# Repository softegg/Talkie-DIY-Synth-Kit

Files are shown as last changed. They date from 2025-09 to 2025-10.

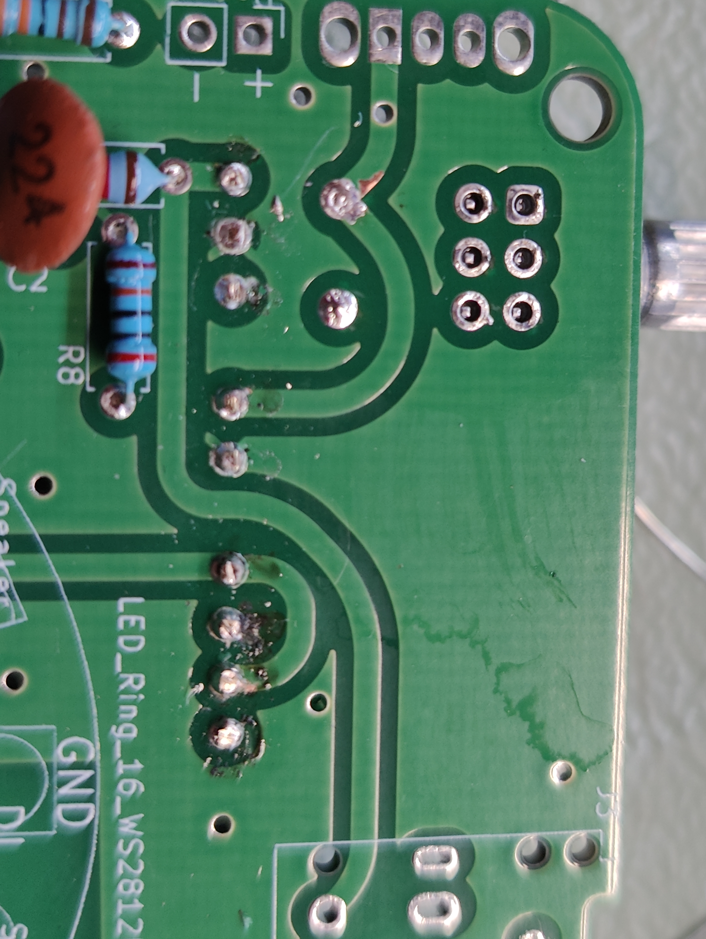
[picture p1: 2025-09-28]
docs/assembly pics/Step 3 amp board final pins.jpg

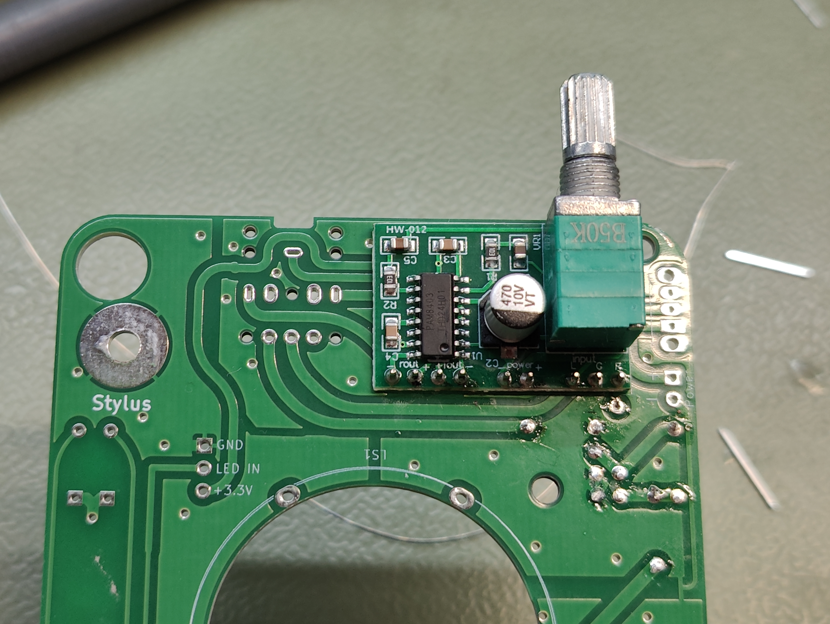
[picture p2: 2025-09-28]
docs/assembly pics/Step 3d amp board complete.jpg

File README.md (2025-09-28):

# Talkie-DIY-Synth-Kit
 Talkie is a DIY Handheld Virtual Analog Music Synthesizer Kit designed by Tina Belmont for the X-Days 2025 event at X-Hain hack+make space, Friedrichshain, Berlin.
 
 This project is based on the Vectorscope Synth ( https://github.com/softegg/Vectorscope-Synth ) made for a Hackaday Berlin 2024 workshop, which was based on the Stylish Trucker Belt Buckle Music Synthesizer ( https://github.com/softegg/Stylish-Trucker-Belt-Synthesizer ) originally made for MAGwest in 2018. Please find the Arduino source code in those projects.
 
 This project is licensed as non-commercial use only. Individuals can use the code and designs to make and modify their own synthesizers, but they cannot sell them without a license from me.
 
 No warranty of correctness or suitablility or safety is provided or honored for this project. Use at your own risk.

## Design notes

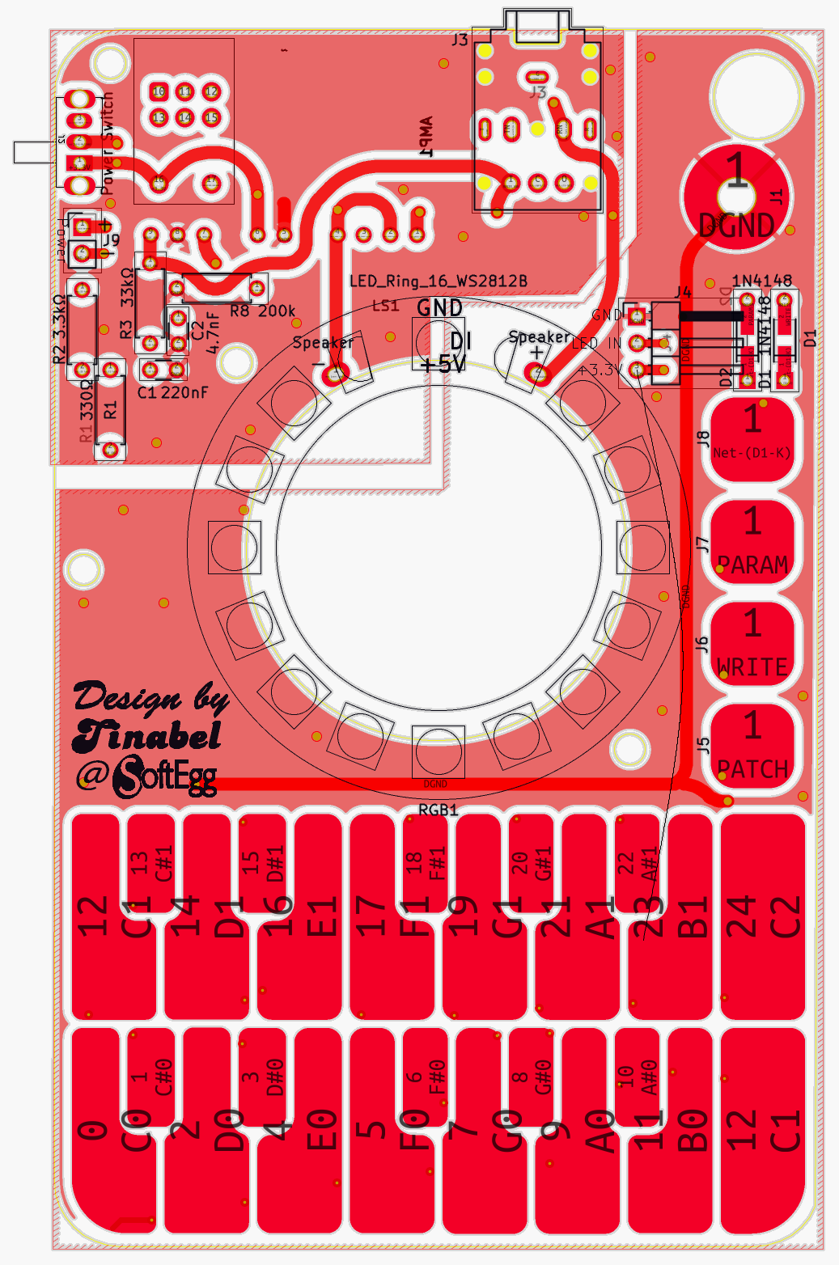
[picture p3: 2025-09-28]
docs/PCB Front + silkscreen.PNG

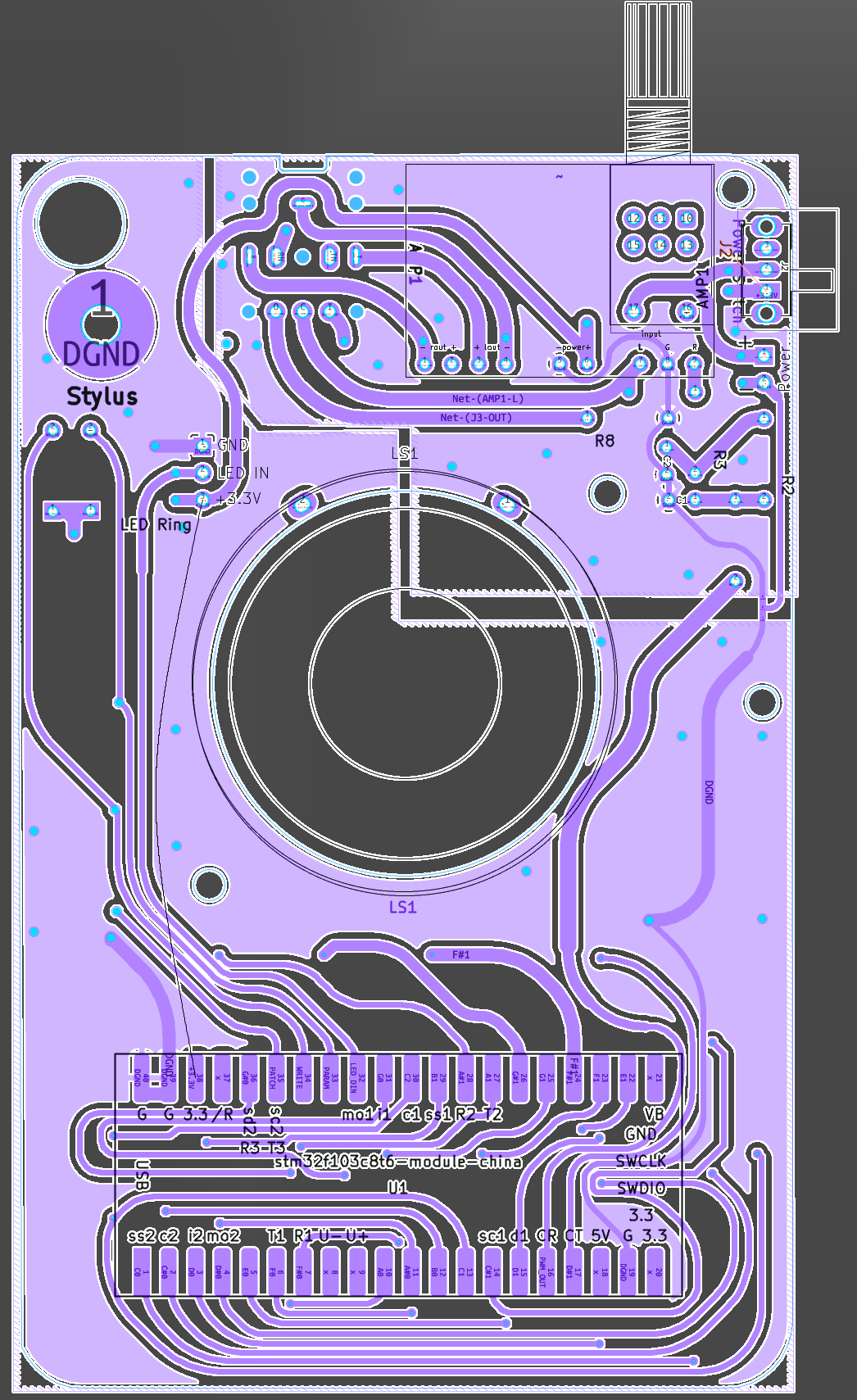
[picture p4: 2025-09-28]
docs/PCB Back + silkscreen and nets.PNG

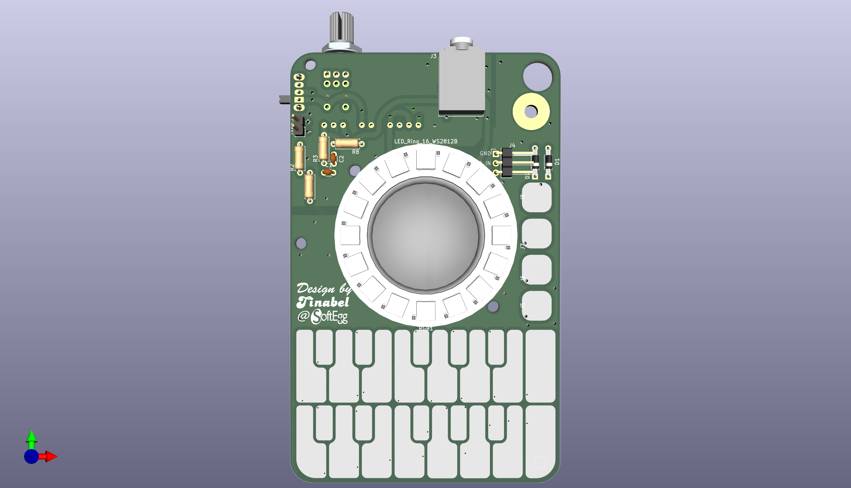
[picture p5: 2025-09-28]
renders/X-DaysSynth-Front.png

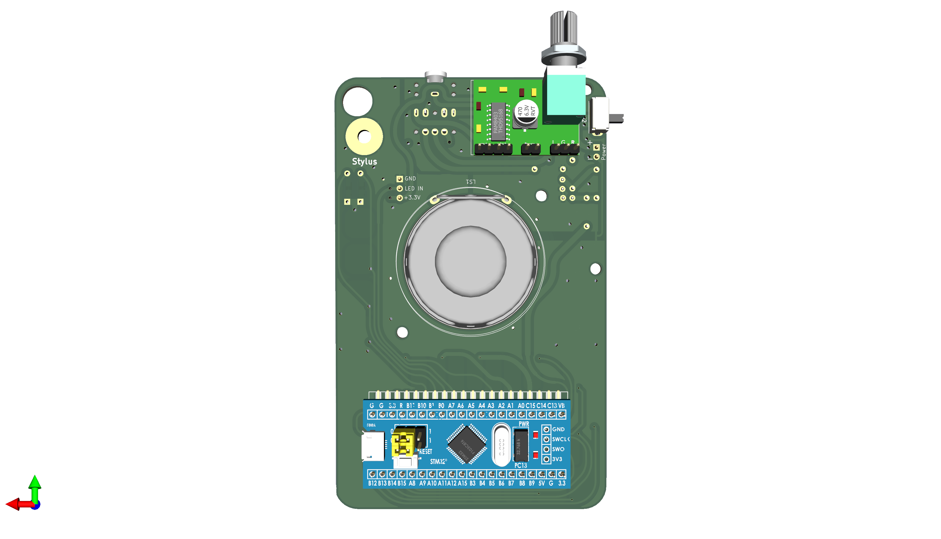
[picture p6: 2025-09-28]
renders/X-DaysSynth-Back-transparent.png

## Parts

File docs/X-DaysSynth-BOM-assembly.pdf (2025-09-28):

Id | Designator Footprint | Quantity Designation | Markings
1 | U1 | PinSocket_1x20_P2.54mm_Horizontal | 2 | | Black, 20 pin socket
2 | U1 | PinHeader_1x20_P2.54mm_Horizontal | 2 | | Yellow
3 | U1 | stm32f103c8t6-module-china-smd | 1 | BluePill board stm32f103c8t6
4 | R1 | R_Axial_DIN0207_L6.3mm_D2.5mm_P7.62mm_Horizontal | 1 | 330Ω | Orange Orange Black Black Brown
5 | R2 | R_Axial_DIN0207_L6.3mm_D2.5mm_P7.62mm_Horizontal | 1 | 3.3kΩ | Orange Orange Black Brown Brown
6 | R3 | R_Axial_DIN0207_L6.3mm_D2.5mm_P7.62mm_Horizontal | 1 | 33kΩ | Orange Orange Black Red Brown
7 | R8 | R_Axial_DIN0207_L6.3mm_D2.5mm_P7.62mm_Horizontal | 1 | 200k | Red Black Black Orange Brown
8 | C2 | C_Disc_D3.0mm_W1.6mm_P2.50mm | 1 | 4.7nF | 473 (smaller, orange/tan)
9 | C1 | C_Disc_D3.0mm_W1.6mm_P2.50mm | 1 | 220nF | 224 (larger, red)
10 | D2,D1 D_DO-35_SOD27_P7.62mm_Horizontal+SMD 2 1N4148
| | A pinheader with some pins removed to fit the amplifier board.
11 | AMP1 | 3-2-4 pinheader for Amplifier board | 1 | Modified pinheader
12 | AMP1 | GF1002-PAM8403_Amplifier_Module_w_bottom_pins | 1 | GF1002-PAM8403 Amp board
13 | J3 | Jack_3.5mm_PJ-307A_Horizontal | 1 | 3.5mm audio jack with switch
14 | LS1 | Speaker 40mm | 1 | Speaker 40mm
15 | J4 | PinHeader_1x03_P2.54mm_Horizontal | 1 | Optional pinheader for LED Ring Black, 3pin right angle
16 | RGB1 | LED RING 16 WS2812B 48mm | 1 | WS2812B 16 LED Ring with wire
17 | | Bodge wire 57mm | 1
18 | J9 | PinHeader_1x02_P2.54mm_Vertical | 1 | 3xAA Battery Holder with wire
Optional
| J2 | SW_Slide_SPDT_Angled_CK_OS102011MA1Q | 1 | Power Switch (not included)

Pin sockets for Bluepill Board 20 pin right angle 2.54mm pin pitch Pinheaders that come with the bluepill board

Connect from LED 3.3V to
bluepill 3.3v

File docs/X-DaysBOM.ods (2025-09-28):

X-Days Synth: Bill of Materials
Name | Quantity (In Project) | Quantity (In Order) | Price of Order | Shipping | Price per unit | URL
16 WS2812B Ring | 1 | 10 | 21.59 € |  | 2.16 € | https://de.aliexpress.com/item/1005004564665321.html
Bluepill STM32F103C8t6 | 1 | 10 | 14.19 € |  | 1.42 € | https://de.aliexpress.com/item/1005009367824674.html
Speaker 3w 4Ω 4cm | 1 | 10 | 10.99 € |  | 1.10 € | https://de.aliexpress.com/item/1005008135472190.html
3.5mm Headphone Jack 307A | 1 | 10 | 1.99 € |  | 0.20 € | https://de.aliexpress.com/item/1005008563098249.html
GF1002-PAM8003 Amplifier Board | 1 | 1 | 0.35 € | 11.72 € | 12.07 € | https://de.aliexpress.com/item/1005003703777732.html
330Ω resistor | 1 | 100 | 0.49 € | 3.18 € | 0.04 € | https://de.aliexpress.com/item/1005006006915852.html
3.3kΩ resistor | 1 | 100 | 0.49 € | 3.18 € | 0.04 € | https://de.aliexpress.com/item/1005006006915852.html
33kΩ resistor | 1 | 100 | 0.49 € | 3.18 € | 0.04 € | https://de.aliexpress.com/item/1005006006915852.html
1N4148 Diode | 2 | 100 | 0.48 € | 3.97 € | 0.04 € | https://de.aliexpress.com/item/1005003194692663.html
200kΩ resistor | 1 | 100 | 0.49 € | 3.18 € | 0.04 € | https://de.aliexpress.com/item/1005006006915852.html
220nF Capacitor | 1 | 100 | 0.25 € | 3.57 € | 0.04 € | https://de.aliexpress.com/item/1005008682681811.html
47nf Capacitor | 1 | 100 | 0.24 € | 3.63 € | 0.04 € | https://de.aliexpress.com/item/1005001496668624.html
Stylus DVM Probe | 1 | 20 | 17.00 € | 0.00 € | 0.85 € | https://de.aliexpress.com/item/1005009697619682.html
PCB | 1 | 30 | 32.60 € | 61.40 € | 3.13 € | https://cart.jlcpcb.com/quote/gerberviewThree/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
Total |  |  |  |  | 21.20 €
 | Units
 | 20 |  |  |  | 423.95 €
 | 25 |  |  |  | 529.94 €
 | 30 |  |  |  | 635.93 €
 | 35 |  |  |  | 741.91 €
 | 45 |  |  |  | 953.89 €
 | 50 |  |  |  | 1,059.88 €

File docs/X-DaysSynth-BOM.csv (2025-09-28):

Id | Designator | Footprint | Quantity | Designation | Supplier and ref
1 | J9 | PinHeader_1x02_P2.54mm_Vertical | 1 | Power
2 | J3 | Jack_3.5mm_PJ-307A_Horizontal | 1 | AudioJackX_Ground_Switch
3 | R3 | R_Axial_DIN0207_L6.3mm_D2.5mm_P7.62mm_Horizontal | 1 | 33kΩ
4 | J8 | SmallRoundTouchPad | 1 | MODE
5 | J6 | SmallRoundTouchPad | 1 | WRITE PATCH
6 | KB1 | StylusKeyboard_noVias | 1 | StylusKeyboardA
7 | C1 | C_Disc_D3.0mm_W1.6mm_P2.50mm | 1 | 220nF
8 | J5 | SmallRoundTouchPad | 1 | PATCH SELECT
9 | J4 | PinHeader_1x03_P2.54mm_Horizontal | 1 | LED Ring
10 | R2 | R_Axial_DIN0207_L6.3mm_D2.5mm_P7.62mm_Horizontal | 1 | 3.3kΩ
11 | R8 | R_Axial_DIN0207_L6.3mm_D2.5mm_P7.62mm_Horizontal | 1 | 200k
12 | D2,D1 | D_DO-35_SOD27_P7.62mm_Horizontal+SMD | 2 | 1N4148
13 | RGB1 | LED RING 16 WS2812B 48mm | 1 | LED_Ring_16_WS2812B
14 | J7 | SmallRoundTouchPad | 1 | PARAM SELECT
15 | R1 | R_Axial_DIN0207_L6.3mm_D2.5mm_P7.62mm_Horizontal | 1 | 330Ω
16 | J1 | SmallRoundTouchPad | 1 | STYLUS
17 | C2 | C_Disc_D3.0mm_W1.6mm_P2.50mm | 1 | 4.7nF
18 | U1 | stm32f103c8t6-module-china-smd | 1 | stm32f103c8t6-module-china
19 | AMP1 | GF1002-PAM8403_Amplifier_Module_w_bottom_pins | 1 | ~
20 | J2 | SW_Slide_SPDT_Angled_CK_OS102011MA1Q | 1 | Power Switch
21 | LS1 | Speaker 40mm | 1 | Speaker

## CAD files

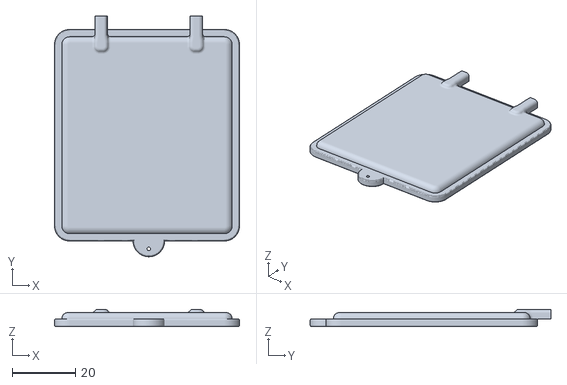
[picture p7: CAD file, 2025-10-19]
enclosure/Talkie - Battery Door.stl
58.6 x 76.2 x 5.50

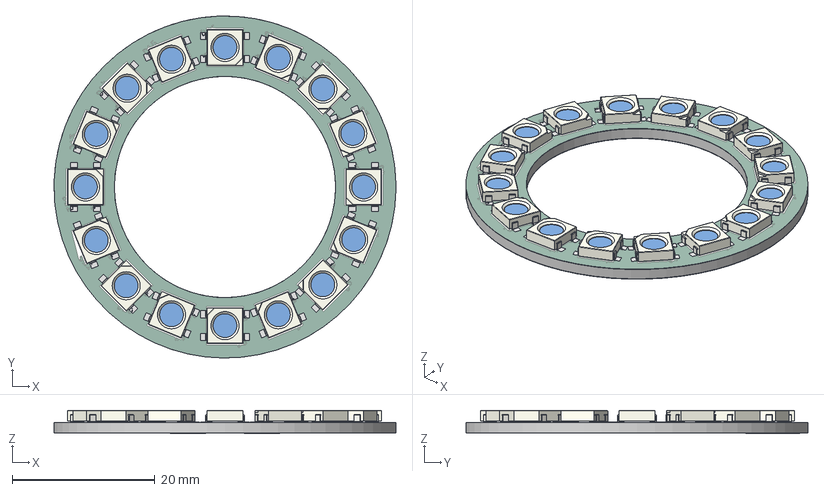
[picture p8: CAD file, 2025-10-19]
KICAD/16 LED Ring/16 LED Ring.step
47.9 x 47.9 x 3.27 mm
LED_WS2812B_PLCC4_5.0x5.0mm_P3.2mm x 16
16 LED Ring_pad
16 LED Ring_silkscreen
16 LED Ring_soldermask
16 LED Ring_PCB

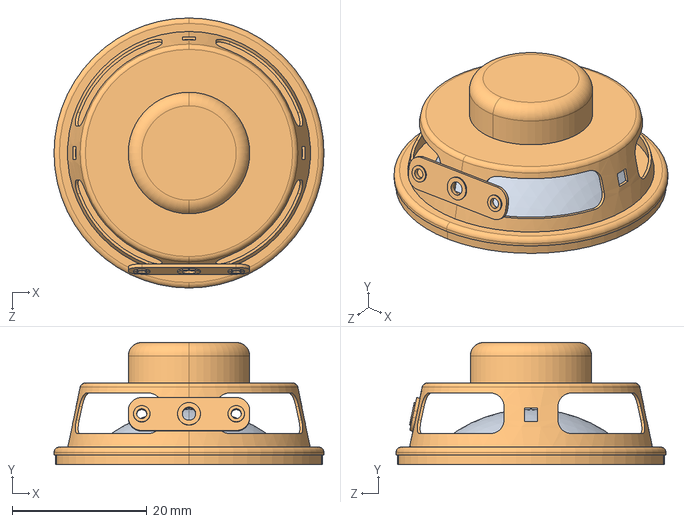
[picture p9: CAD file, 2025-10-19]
KICAD/Speaker/speaker 40mm.STEP
40.0 x 18.1 x 40.0 mm

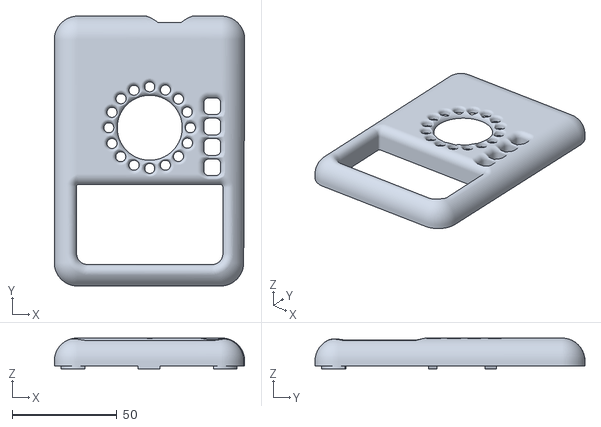
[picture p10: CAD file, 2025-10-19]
enclosure/Talkie - Top.stl
91.0 x 129.0 x 14.8

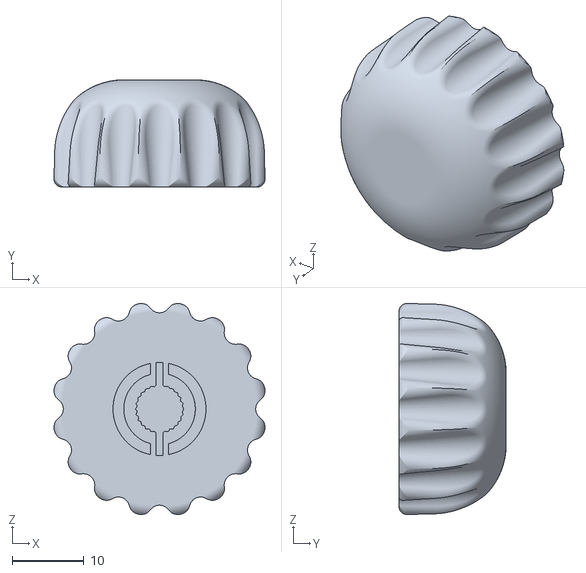
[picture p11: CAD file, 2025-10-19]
enclosure/Talkie - Knob.stl
29.5 x 15.0 x 29.5

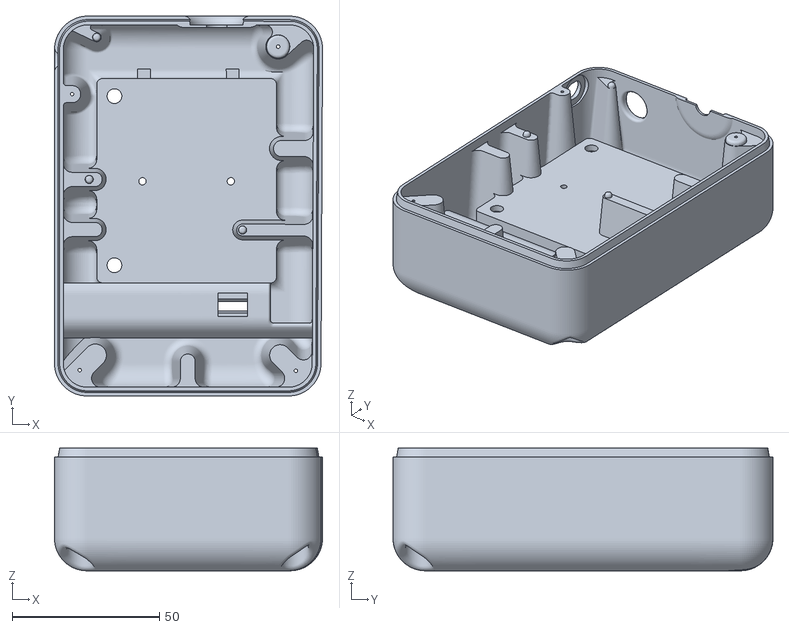
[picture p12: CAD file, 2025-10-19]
enclosure/Talkie - Bottom.stl
91.0 x 129.0 x 41.6

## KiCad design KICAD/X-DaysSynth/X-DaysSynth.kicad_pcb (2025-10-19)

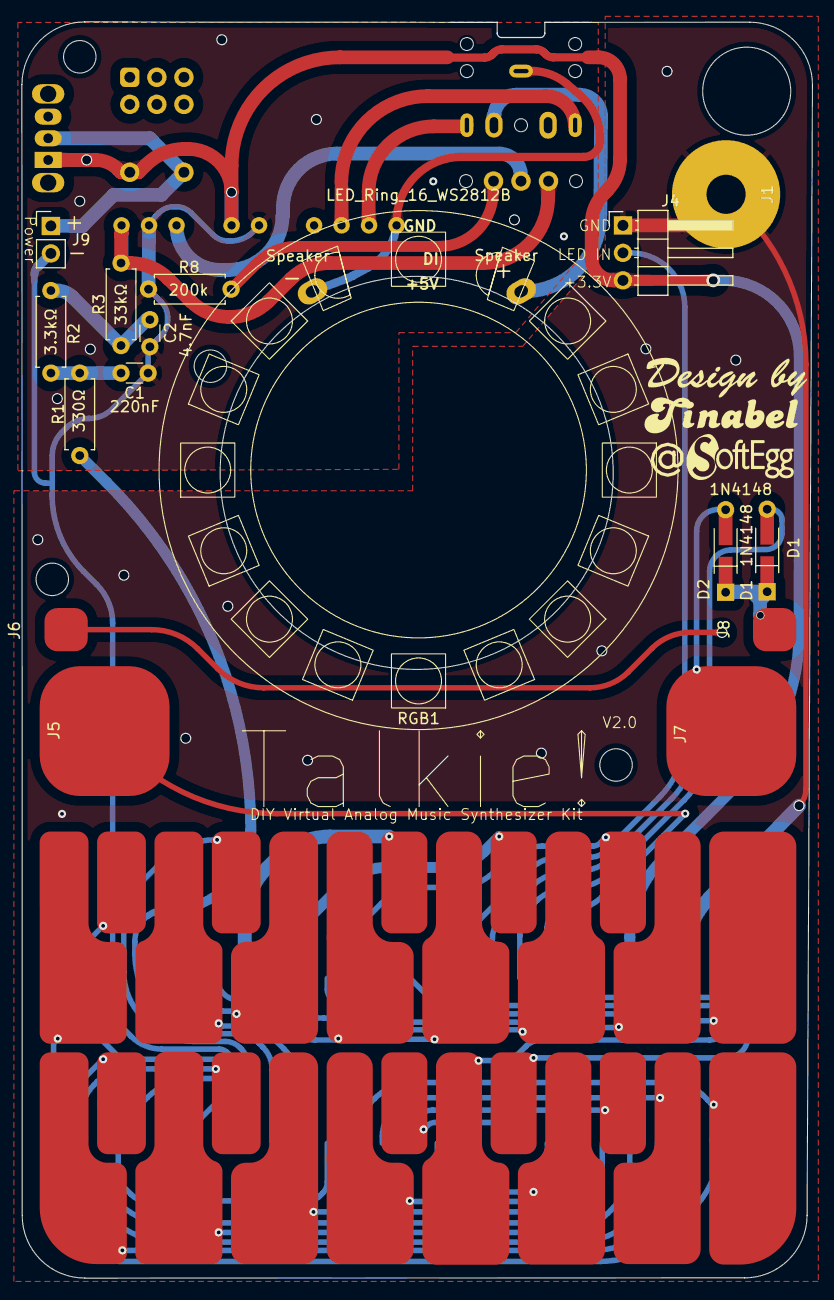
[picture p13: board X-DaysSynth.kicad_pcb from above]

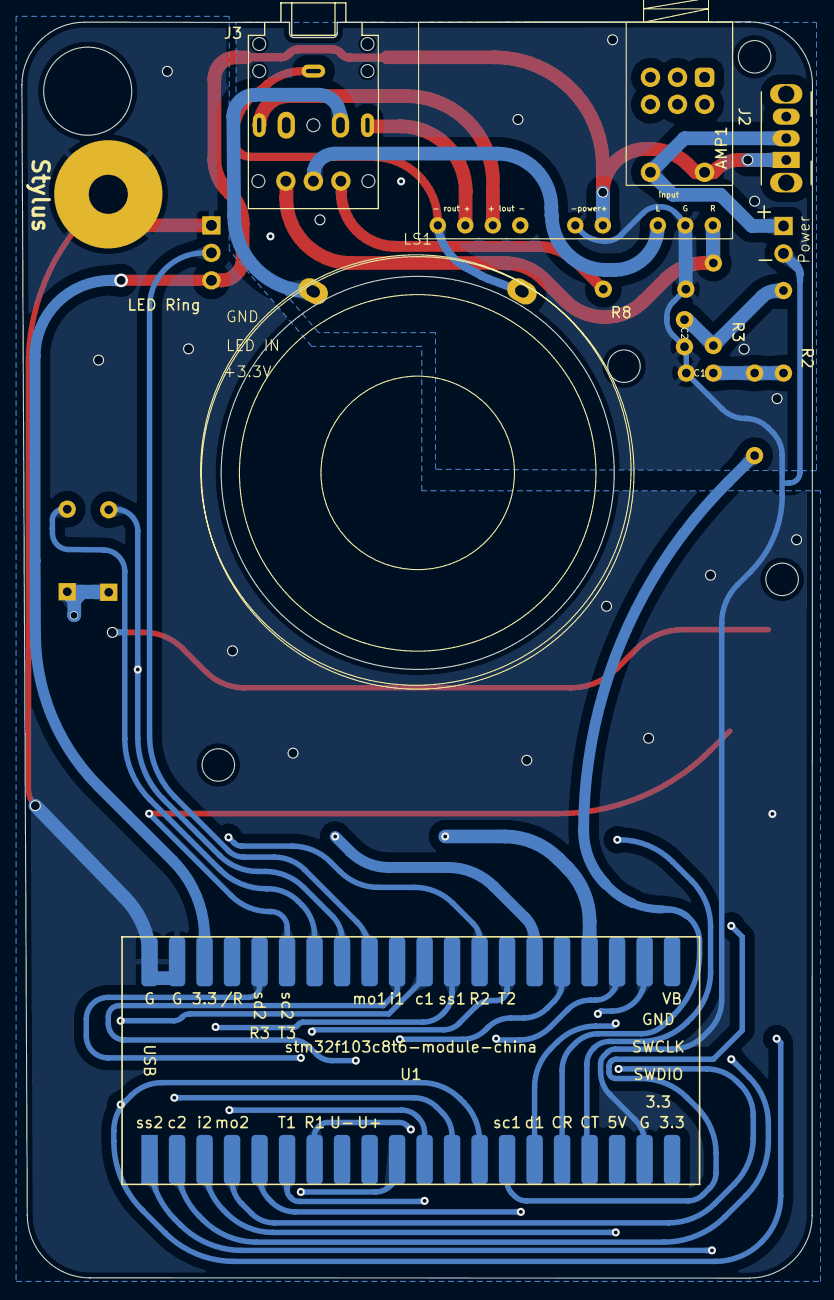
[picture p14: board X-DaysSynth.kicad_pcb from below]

Board: 2 copper layers, 73.0 x 116.0 mm, 23 parts (6 on the bottom side), 45 nets.

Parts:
AMP1: GF1002-PAM8403_Amplifier_Module_w_bottom_pins
C1: 220nF; C_Disc_D3.0mm_W1.6mm_P2.50mm
C2: 4.7nF; C_Disc_D3.0mm_W1.6mm_P2.50mm
D1, D2: 1N4148; D_DO-35_SOD27_P7.62mm_Horizontal+SMD
J1: STYLUS; SmallRoundTouchPad
J2: Power Switch; SW_Slide_SPDT_Angled_CK_OS102011MA1Q
J3: AudioJackX_Ground_Switch; Jack_3.5mm_PJ-307A_Horizontal
J4: LED Ring; PinHeader_1x03_P2.54mm_Horizontal
J5: PATCH SELECT; SmallRoundTouchPad
J6: WRITE PATCH; SmallRoundTouchPad
J7: PARAM SELECT; SmallRoundTouchPad
J8: MODE; SmallRoundTouchPad
J9: Power; PinHeader_1x02_P2.54mm_Vertical
KB1: StylusKeyboardA; StylusKeyboard_noVias
LS1: Speaker; Speaker 40mm
NT1: NetTie_3; NetTie-3_SMD_Pad0.5mm
R1: 330Ω; R_Axial_DIN0207_L6.3mm_D2.5mm_P7.62mm_Horizontal
R2: 3.3kΩ; R_Axial_DIN0207_L6.3mm_D2.5mm_P7.62mm_Horizontal
R3: 33kΩ; R_Axial_DIN0207_L6.3mm_D2.5mm_P7.62mm_Horizontal
R8: 200k; R_Axial_DIN0207_L6.3mm_D2.5mm_P7.62mm_Horizontal
RGB1: LED_Ring_16_WS2812B; LED RING 16 WS2812B 48mm
U1: stm32f103c8t6-module-china; stm32f103c8t6-module-china-smd

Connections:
+3.3V: AMP1.6 (POWER+), AMP1.16 (SWITCH1), J2.1, J4.3, U1.38 (3V3)
/A0: KB1.9 (A0), U1.10 (A15/JTDI)
/A1: KB1.21 (A1), U1.27 (A2/U2TX)
/A#0: KB1.10 (A#0), U1.11 (B3/JTDO)
/A#1: KB1.22 (A#1), U1.28 (A3/U2RX)
/AUDIO_LOW: AMP1.9 (R), J3.I (IN), R3.1
/B0: KB1.11 (B0), U1.12 (B4/JnTRST)
/B1: KB1.23 (B1), U1.29 (A4/NSS1)
/C0: KB1.0 (C0), U1.1 (B12/NSS2)
/C1: KB1.12 (C1), U1.13 (B5)
/C2: KB1.24 (C2), U1.30 (A5/SCK1)
/C#0: KB1.1 (C#0), U1.2 (B13/SCK2)
/C#1: KB1.13 (C#1), U1.14 (B6/SCL1a/U1TXb)
/D0: KB1.2 (D0), U1.3 (B14/MISO2)
/D1: KB1.14 (D1), U1.15 (B7/SDA1a/U1RXb)
/D#0: KB1.3 (D#0), U1.4 (B15/MOSI2)
/D#1: KB1.15 (D#1), U1.17 (B9/SDA1b/CANTX)
/DGND: J1.1, J4.1, NT1.1, U1.19 (GND), U1.39 (GND), U1.40 (GND)
/E0: KB1.4 (E0), U1.5 (A8/MCO)
/E1: KB1.16 (E1), U1.22 (C13)
/F0: KB1.5 (F0), U1.6 (A9/U1TXa)
/F1: KB1.17 (F1), U1.23 (C14/OSC32_IN)
/F#0: KB1.6 (F#0), U1.7 (A10/U1RXa)
/F#1: KB1.18 (F#1), U1.24 (C15/OSC32_OUT)
/G0: KB1.7 (G0), U1.31 (A6/MISO1)
/G1: KB1.19 (G1), U1.25 (A0/WKUP)
/G#0: KB1.8 (G#0), U1.36 (B11/SDA2/U3RX)
/G#1: KB1.20 (G#1), U1.26 (A1)
/GND-IN: J9.2, NT1.2
/LED_DIN: J4.2, U1.32 (A7/MOSI1)
/PARAM: D2.2 (A), J7.1, U1.33 (B0)
/PATCH: J5.1, U1.35 (B10/SCL2/U3TX)
/PWM_OUT: R1.2, U1.16 (B8/SCL1b/CANRX)
/WRITE: D1.2 (A), J6.1, U1.34 (B1)
GNDA: AMP1.5 (POWER-), AMP1.8 (G), C1.2, C2.2, NT1.3, R8.2
unnamed: AMP1.7 (L), J3.C (COM)
unnamed: AMP1.3 (LOUT+), J3.T
unnamed: AMP1.2 (ROUT+), J3.R
unnamed: AMP1.1 (ROUT-), J3.G, LS1.1
unnamed: AMP1.17 (SWITCH2), J2.2, J9.1
unnamed: C1.1, R1.1, R2.2
unnamed: C2.1, R2.1, R3.2
unnamed: D1.1 (K), D2.1 (K), J8.1
unnamed: J3.O (OUT), R8.1
unnamed: J3.RN, LS1.2

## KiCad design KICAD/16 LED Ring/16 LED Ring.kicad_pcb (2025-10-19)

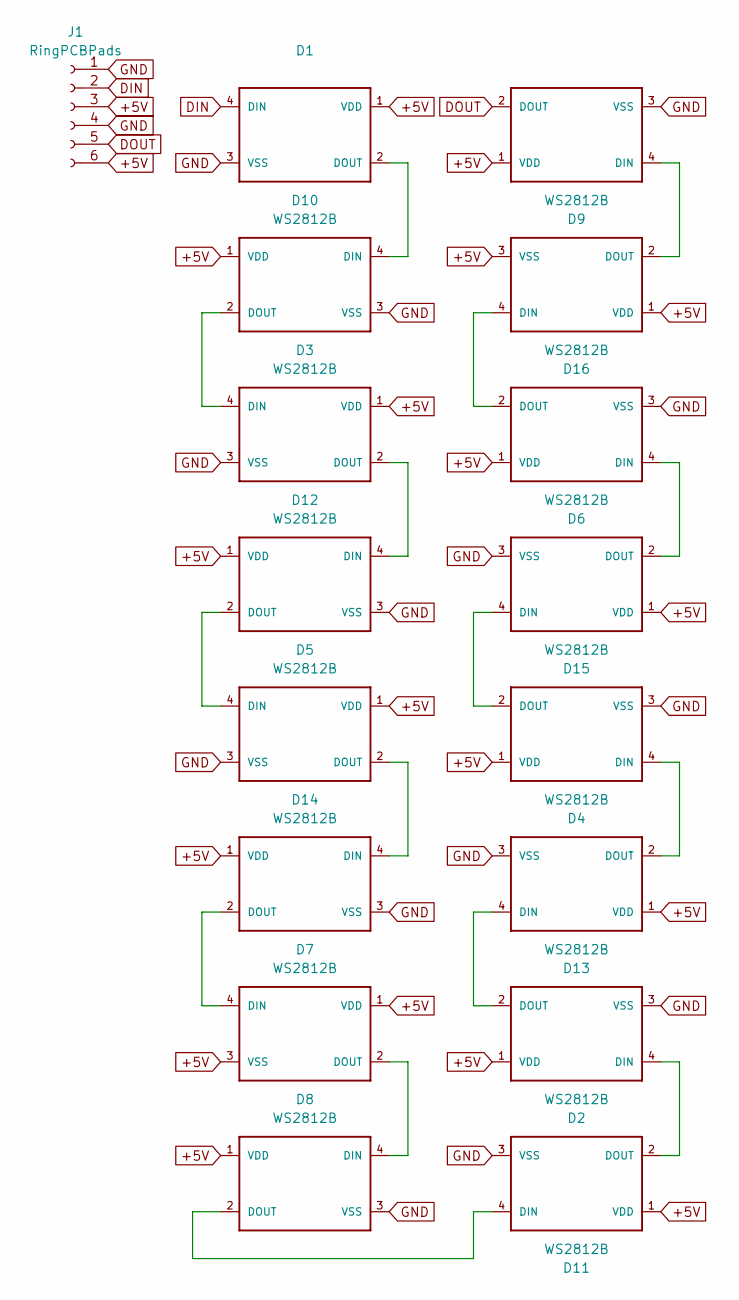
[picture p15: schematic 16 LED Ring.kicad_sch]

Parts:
D1, D2, D3, D4, D5, D6, D7, D8, D9, D10, D11, D12, D13, D14, D15, D16: WS2812B
J1: RingPCBPads; LED RING 16 WS2812B 48mm standalone

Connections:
+5V: D1.1 (VDD), D2.1 (VDD), D3.1 (VDD), D4.1 (VDD), D5.1 (VDD), D6.1 (VDD), D7.1 (VDD), D7.3 (VSS), D8.1 (VDD), D9.1 (VDD), D10.1 (VDD), D11.1 (VDD), D12.1 (VDD), D13.1 (VDD), D14.1 (VDD), D15.1 (VDD), D16.1 (VDD), D16.3 (VSS), J1.3, J1.6
DIN: D1.4 (DIN), J1.2
DOUT: D9.2 (DOUT), J1.5
GND: D1.3 (VSS), D2.3 (VSS), D3.3 (VSS), D4.3 (VSS), D5.3 (VSS), D6.3 (VSS), D8.3 (VSS), D9.3 (VSS), D10.3 (VSS), D11.3 (VSS), D12.3 (VSS), D13.3 (VSS), D14.3 (VSS), D15.3 (VSS), J1.1, J1.4
unnamed: D1.2 (DOUT), D10.4 (DIN)
unnamed: D7.2 (DOUT), D8.4 (DIN)
unnamed: D3.4 (DIN), D10.2 (DOUT)
unnamed: D8.2 (DOUT), D11.4 (DIN)
unnamed: D2.4 (DIN), D11.2 (DOUT)
unnamed: D3.2 (DOUT), D12.4 (DIN)
unnamed: D5.4 (DIN), D12.2 (DOUT)
unnamed: D2.2 (DOUT), D13.4 (DIN)
unnamed: D4.4 (DIN), D13.2 (DOUT)
unnamed: D5.2 (DOUT), D14.4 (DIN)
unnamed: D7.4 (DIN), D14.2 (DOUT)
unnamed: D4.2 (DOUT), D15.4 (DIN)
unnamed: D6.4 (DIN), D15.2 (DOUT)
unnamed: D6.2 (DOUT), D16.4 (DIN)
unnamed: D9.4 (DIN), D16.2 (DOUT)

Board: 2 copper layers, 17 parts (0 on the bottom side), 19 nets, no tracks yet.

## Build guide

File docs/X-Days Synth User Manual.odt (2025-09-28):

# X-Hain hack+make space

X-Days

Build a Synthesizer Workshop

Talky

# Micro Stylus Synth Kit

### Operations Manual

##### By Tina Belmont

X-Hain hack+make space X-Days Build a Synthesizer Workshop

Talky Micro Stylus Synth Kit Operations Manual

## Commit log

2025-09-28 As Manufactured for X-Days
    [16 LED Ring.kicad_pcb, 16 LED Ring.kicad_sch, X-DaysBOM.ods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]
2025-10-19 LED ring 3d models updated PCB and schematic Logo Text first draft enclosures 3d models
    [16 LED Ring.kicad_pcb, 16 LED Ring.step, Talkie - Battery Door.stl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]
